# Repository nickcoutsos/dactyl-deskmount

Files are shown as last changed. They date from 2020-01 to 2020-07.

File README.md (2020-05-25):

# dactyl-deskmount
---
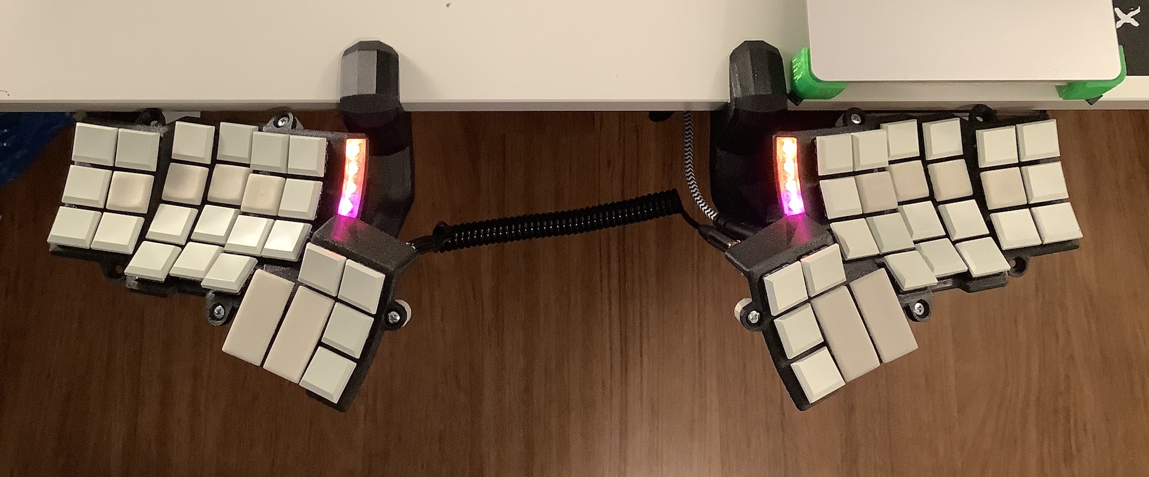
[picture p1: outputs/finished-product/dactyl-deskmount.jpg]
Dactyl and desk mounting hardware


_[(3D Preview of assembled keyboard)](outputs/preview.stl)_

_[(More photos of the finished product)](outputs/finished-product/)_

## Goal

Essentially, make a variant of the [dactyl-keyboard] that doesn't impose
significant extra height above my desk surface.

I previously designed and built the "[dactyl-flatpacked]", a Dactyl made from
slotted acrylic pieces instead of 3D printed, and ended up loving the keyboard.
Like most non-planar keyboards it has an issue with overall height. The lowest
row requires my wrist/palm needs to clear around 4cm, and unfortunate
combinations of desk-chair-user height can exacerbate things. Ultimately it has
taught me to properly float my wrists while typing, but I still wanted to see
what else could be done.

Another goal I had was to have a pure and simple OpenSCAD version of the dactyl
that wouldn't require the complexity of compiling and executing Clojure to
generate unreadable OpenSCAD code. This part started out pretty well but over
time I got tired of limitations around code organization and stopped trying so
hard to keep features modular while still having something aesthetically
pleasing.

I still stand by working directly in OpenSCAD, but if I were to start
over or dedicate significant time to refactoring I would look into more of the
community OpenSCAD libraries for things like generating hulls from profiles
instead of mimicking triangle hulls and such that I saw in the origin dactyl
code.

## Inspiration

Through the mechanical keyboard subreddit I came across a couple of keyboard
mounting designs that helped me see the possibility of using ball-and-socket
mounts.

**ElliotCable: [Ergovox]**

This ergodox keyboard uses RAM mounts screwed into the bottom of a standing desk
allowing for a fully vertical (or any angle, really) keyboard orientation.

**Martin Körner: [Georgi stand with trackball]**

This georgi uses ball camera mounts attached to a tripod, removing the desktop
from the equation altogether. With the tripod you can precisely control height
and the trackball mount is a nice bonus as well.

## Design Considerations

**Desk mounted via clamps**

The tripod stand is cool but I work at a desk. Unfortunately when I'm in the
office it isn't my desk so stability is sacrificed to avoid drilling holes.

**Camera ball mounts**

I don't want to go to all the trouble of building a keyboard only to wonder if a
steeper tenting angle would be better. I also get to control the pitch and yaw
if I like. I had a lot of misgivings about this. Ideally it would be positioned
so that the majority of the the force put into the keyboard goes straight
through the ball to avoid torque causing the ball to slip.

Unfortunately putting the ball mount directly underneath my hand would take up
room underneath the keyboard and cause problems for the sitting position. I made
the concession of offsetting the mount a little with the hope that by the time I
begin to see obvious slippage I will have found an angle I like and print static
arms to clamp onto my desk. Worst case scenario, I can print a more traditional
base and use the keyboard on my desktop like an animal.

**Keycaps and layout**

I use choc low-profile switches because I had them leftover from an earlier
iteration I didn't end up liking. I designed and printed custom variations of
the 2u keycaps (because, quite simply, I like the Dactyl's thumb cluster) and
deep-dished homing keycaps.

The same positioning algorithm from the original Dactyl is used but with a
slight outward pivot of the pinky columns, and removed keys:

* no number row because I hate it
* pinky keys removed from row 4

Were I a braver person I would remove even more keys (the entire pinky columns)
and learn to love QMK combos but I never properly made sense of the config
options like `PERMISSIVE_HOLD` and `IGNORE_MOD_TAP_INTERRUPT` which made for a
bad experience in the past.

**LEDs**

I want to have visual indicators for things like Caps Lock (because I find caps
lock useful) and potentially notifications pushed from the host via Raw HID.
Admittedly I do think a few subtle lights can add to the keyboard's aesthetics.

## Mounting hardware

* 3d printed desk clamps
  * I include a cutout for 1/4"x5/16" tee-nut.
  * a 1/4"-20 x 1 1/4" hex bolt (with 3d printed knob and swivel plate) are used
    for tightening.
* 1/4" ball mount (I used a [ball mount tripod adapter] from AliExpress)
  * This attaches to my 3d printed clamp via a couple of m4 screws
* 3d printed keyboard bottom mount attached to the top of the ball mount via
  another tee-nut.
    * at the beginning I set out to use heat-set inserts like I've seen on many
      other projects but couldn't find a source for the right kind in a useful
      quantity.
    * I'm finding tee-nuts to be incredibly useful in 3d printed projects when I
      want to securely fasten things to a single screw.
* 3d printed keyboard plate attaches to 3d printed mount via m3 screws.
  * the design uses three m3 mounting holes on the keyboard plate matching up
    with three holes on the mount (one on the far edge of the thumb cluster and
    two at the top and bottom of the index finger column).
  * there are two more unused screw holes on the pinky finger column in case I
    want to re-design a more robust bottom mount.
* another 3d printed mount hanging underneath the thumb cluster holds a 24-pin
  wide IC socket for the pro micro controller. Ribbon cables conned the socket
  pins to the keyboard matrix and TRRS socket. A stripped micro USB connector
  connects from a sturdier micro USB socket breakout board to the pro micro.

## Pre-rendered parts

All printable pieces are pre-rendered (for my specific setup) and available in
[outputs/pre-rendered/](outputs/pre-rendered):

* [bottom-mount](outputs/pre-rendered/bottom-mount.stl)
* [choc-keycap-1u](outputs/pre-rendered/choc-keycap-1u.stl)
* [choc-keycap-1u-index](outputs/pre-rendered/choc-keycap-1u-index.stl)
* [choc-keycap-2u](outputs/pre-rendered/choc-keycap-2u.stl)
* [clamp-knob](outputs/pre-rendered/clamp-knob.stl)
* [clamp-swivel-plate](outputs/pre-rendered/clamp-swivel-plate.stl)
* [led-diffuser](outputs/pre-rendered/led-diffuser.stl)
* [plate](outputs/pre-rendered/plate.stl)
* [socket-mount](outputs/pre-rendered/socket-mount.stl)
* [table-hook](outputs/pre-rendered/table-hook.stl)

[dactyl-keyboard]:https://github.com/adereth/dactyl-keyboard/
[dactyl-flatpacked]:https://github.com/nickcoutsos/dactyl-flatpacked/
[Georgi stand with trackball]:https://stenoblog.com/georgi-stand-with-trackball/
[Ergovox]:https://www.reddit.com/r/MechanicalKeyboards/comments/8ib8pi/something_a_little_different_the_ergovox/
[ball mount tripod adapter]:https://www.aliexpress.com/item/4000183944867.html

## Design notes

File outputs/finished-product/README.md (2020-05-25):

# Finished product

## Top view

Assembled keyboard in use

This is my home computer setup as of 2020-05-18. A cheap IKEA sit/stand desk, my
newly completed desk-mounted dactyl keyboard, and an older Apple Magic Trackpad.

In this shot you can also see the LEDs running an animation I made to just cycle
through a narrow range of hues to avoid being too jarring. Eventually this will
signal notifications on the host computer but for now I have the lights turned
off.

Earlier in the design of the keyboard I considered another mount to keep the
trackpad at the same level as the keyboard but I'm really surprised at how
comfortable it is to use positioned just past the right hand keyboard. This is
great for me because despite having switched to a trackball mouse several months
earlier, nothing beats precision scrolling.

## Below

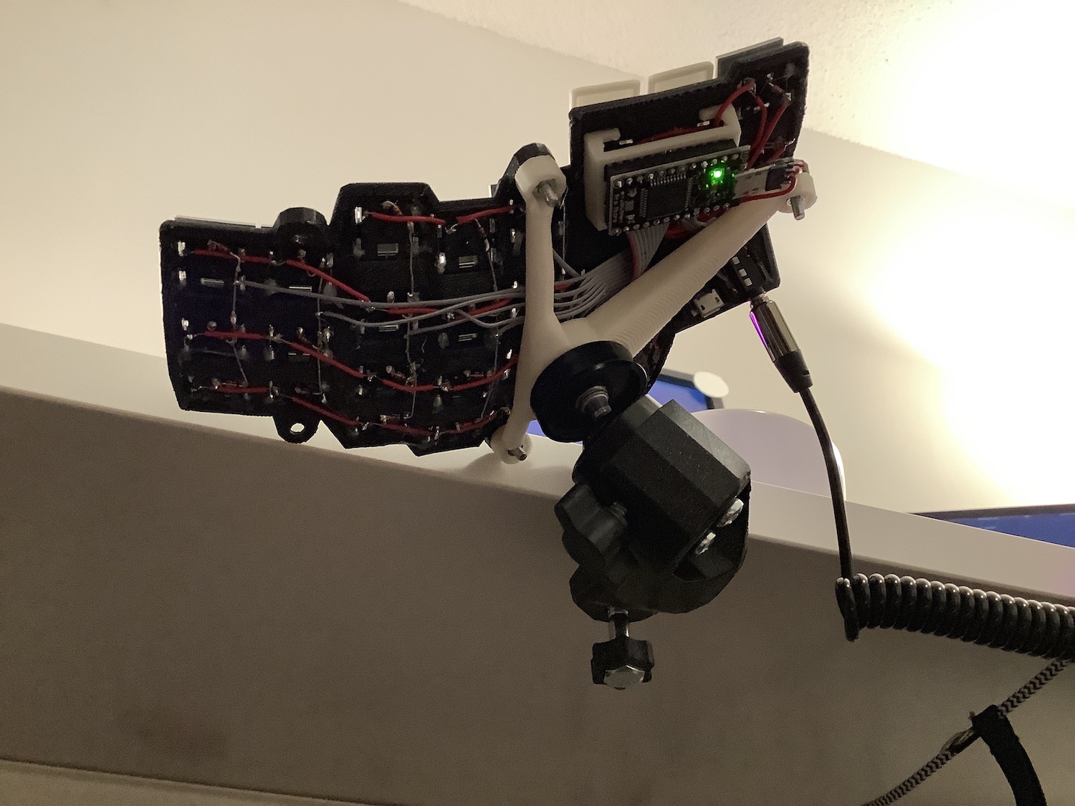
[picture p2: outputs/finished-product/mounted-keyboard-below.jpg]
Keyboard from below


The wiring is pretty exposed. I prefer this simplicity to a lot of the keyboard
cases that add height without giving you any real benefits. It's a DIY keyboard
already and, in my opinion, a fully enclosed case doesn't make it look more
professional.

I did have some concerns about having this in an office setting where delicate
components are exposed to stray dogs but that's moot for the foreseeable future.

Anywho, one other nice benefit to mounting this off the front of the desk is the
ability to run the USB cable under my desk and out of sight.

## Mount

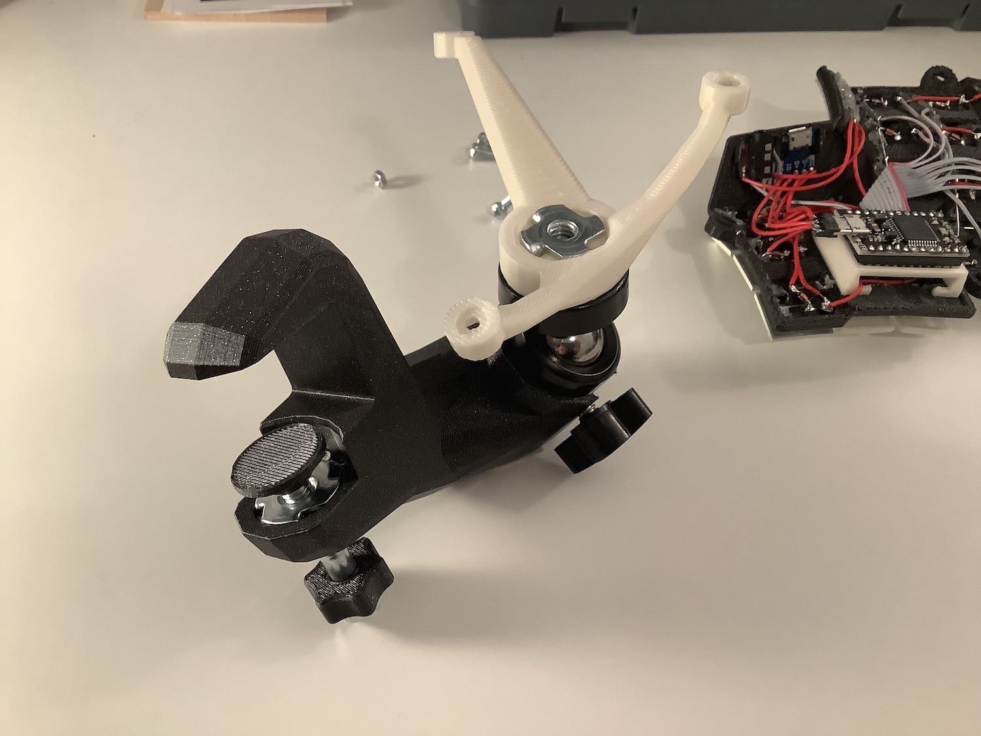
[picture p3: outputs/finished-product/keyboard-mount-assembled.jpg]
Mounting hardware assembled


This is the assembled keyboard mount without the keyboard.

The main black print is the [table hook](../pre-rendered/table-hook.stl) and in the clamp part (left) is the [swivel plate](../pre-rendered/clamp-swivel-plate.stl)
(it doesn't really stay in place when not clamped) sitting on top of a 1/4" hex
bolt screwed into a tee-nut and the hex head covered by a small comfortable
[knob](../pre-rendered/clamp-knob.stl).

The other end holds an off-the-shelf ball mount, and on top of that in white is
the [bottom mount](../pre-rendered/bottom-mount.stl) to which the keyboard 
attaches with 3 sets of m3 screws and nuts.

## Wiring

Here's a rough look at the wiring for the left half.

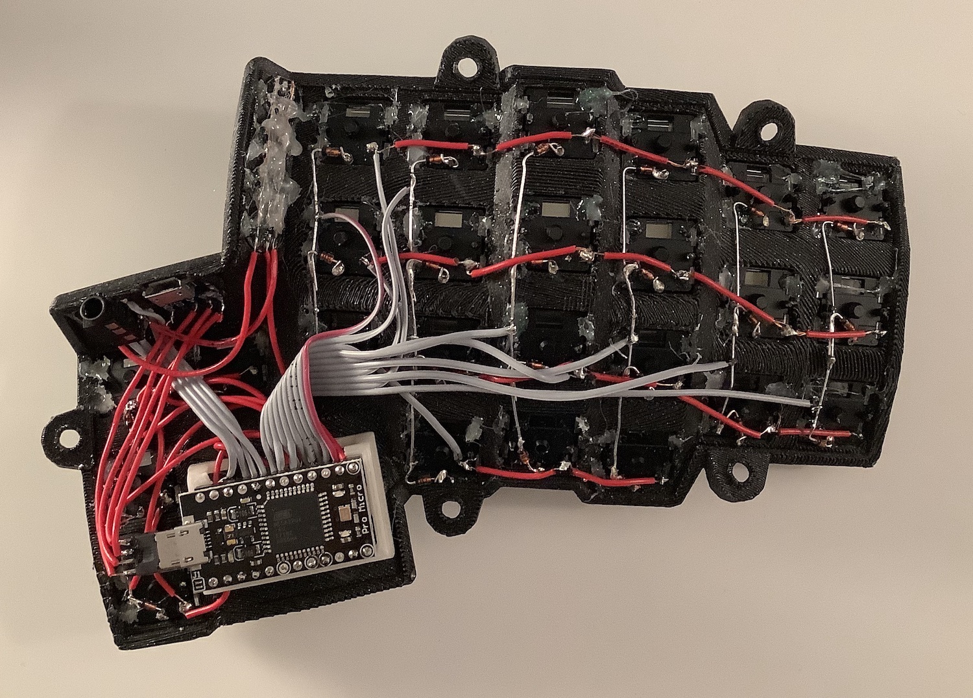
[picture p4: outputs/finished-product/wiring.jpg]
Left hand wiring


All of the switches are hot-glued into the plate for extra security. As an added
bonus these glue sticks contain glitter.

The finger cluster wiring is pretty clean considering I removed the diodes from
an earlier version for re-use, but the thumb cluster is where all the action is
and it's hard to see what's going on there.

Right over the 2u thumb keys I have the [socket-mount](../pre-rendered/socket-mount.stl)
super-glued and the 24-pin IC socket sits inside. A couple of ribbon cables 
connect it to the finger cluster and TRRS breakout board, as well as another 8
individual wires for the thumb matrix and the LED chain. Lastly, a gutted micro
USB connector connects the micro USB breakout board to the mounted pro micro.

The pro micro has diode leg pins to hold it firmly into place in the IC socket,
and with all of the other wires the socket doesn't actually need glue to stay in
place.

The LED column (left of all the finger switches) is hard to make out underneath
all of the hot glue. This is partly to make sure they stay in place but also to
shield the bare copper wires used to connect all of the VCC and GND pads.

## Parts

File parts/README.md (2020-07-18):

# Parts

OpenSCAD files in this directory are individually printable pieces used to
assemble the keyboard.

Files under `placeholders/` are approximations of existing parts (screws, PCBs,
etc.) that shouldn't be printed, but are used to help provide a clearer picture
of the assembly and/or for subtraction. These modules will often have optional
parameters like `$clearance` and `footprint` to help create appropriately sized
negative spaces in the printed pieces.

## Printable Parts

### `plate.scad`

This is the main component. It connects a number of plates arranged according to
the defined row and column sizes and curvatures. It also includes a trim made of
a quarter-round profiled edge, a space for a column of 3535 PCB LEDs and a few
m3-sized screw holes to attach to the keyboard's bottom-mount.

### `socket-mount.scad`

The socket mount gives me a place to attach my pro micro socket hanging below
the thumb cluster. When I assembled everything I ended up cutting out most of
the horizontal pieces so that I could solder directly to the socket before
gluing things down.

In retrospect, this could have been simplified and printed as part of the plate
itself but I was worried about how well it would come out given that it would be
printing on top of support material.

### `led-diffuser.scad`

I had few versions of this, but the idea is to print a very thin (1 line thick)
cover in transparent or light coloured filament to diffuse the LED light. It
worked ok. The important thing was to not blind anybody catching an eyeful of my
keyboard's lights, but printing it in translucent filament gives a very pretty
look. If you render the script standalone (instead of importing the module) its
in a standing position with manually generated support for printing stability.

In the end I settled on a solid pyramid-like pattern hoping to get interesting
refraction of the light, but if I were to do this again I would redesign the
plate so that this part doesn't have curves on multiple axis and cut a piece of
acrylic for the LEDs to shine through the edge.

### `bottom-mount.scad`

This may be the lightest piece that takes most of the strain. It attaches to the
ball mount (secured in place via a tee-nut) with arms extending to screw holes
on the plate that fasten via m3 screw and hex nut.

__**NEW:**__ after a bit of use I was happy with the stability fo the camera
mount, but the plate itself would flex a fair bit when pressing keys on outer
columns (particularly modifiers like shift and layer toggles where I'm holding
the key down). The bottom mount has been updated to add additional branches to
connect to the outer column screw holes, and all arms have been made thicker.

Now the main source of flex comes from the table hook.

### `table-hook.scad`

The table hook (which includes the `clamp.scad` part) is a holder for the ball
mount, a short arm, and a clamp that attaches to the edge of the desk. I have
a separate file for the clamp that that I could print and test it separately but
for consistency it should be moved and the table-hook file should include a
module that cuts it down to the testable printable section.

This piece can be printed without supports if you're ok a not-so-nice bottom
side (and that your printer is good enough but I guess that goes for everything)

### `choc.scad`

Most of my keyboard uses regular Kailh Choc 1u keycaps, but I made a custom
version to print my own 2u and scooped 1u (with bump) versions.

This is not the same as `placeholders/keycap.scad` which doesn't include the
stem or cavity (or surface detail).

## Plate "atoms"

Modules in this directory are the "atoms" that make up the full plate. On their
own they are useless but the intention is to hull the pieces together.

## Placeholders

Placeholder parts

_(left to right: `led`, `hex_nut`, `hex_bolt`, `socket`, `kailh_choc_keycap`,
`kailh_choc_switch`, `m3_nut`, `m3_screw`, `micro_usb_breakout`, `pro_micro`,
`tee_nut`, `trrs_breakout`)_

_(top to bottom: normal, `$detail=true`, `$detail=true; $clearance=1`)_

### `3535-led.scad`

Everything I do is handwired so surface mount components aren't really an option.
You can find ws2812b LEDs on individual PCBs (including capacitor and resistor)
which makes things a little easier, so I use them happily. This placeholder
accounts for the placement of the capacitor and resistor so that it can be
subtracted from the plate, leaving a helpful socket.

When soldering the chain of LEDs together I found it helpful to take a length
of wire, strip of the insulation, twist the strands together, and solder that
across each line of pads (VCC, DIn/DOut\*, GND) instead of cutting individual
wires and soldering them one at a time. 

\*Although VCC and GND on the LEDs are technically parallel, the signal line
is serial so if you do this you absolutely need to cut the wires to so that the
DI and DO pads of the same PCB are NOT connected.

### `ball-mount.scad`

This module gives me a visual of the ball mount part with a couple of extras:

1. I can render child modules that are "attached" to the mount
2. I can pass in transformations that it will apply to the base and mount to
   let me pivot things.
3. It will pass the inverse of those pivots to the child modules so that I can
   undo transformations as needed.

### `ic-socket.scad`

A 24 pin wide IC socket.

### `keycap.scad`

Rough approximation of a kailh choc keycap. It looks for OpenSCAD special
variables (`$u`, `$h`, and `$rot`) that may be set by the positioning module to
give us per-key customizations. The override definitions for the thumb cluster
makes use of this to implement the tall "vertical" keycaps as rotated "wide"
keycaps.

It can also look for `$key_pressed` to translate the keycap downward so you can
visualize the space between keys when pressed vs unpressed.

### `keyswitch.scad`

Rough approximation of a kailh choc keyswitch. This visual is helpful to plan
out where the switch pins will end up in the final layout, although I think I
might be the only person in the world not rotating them 180 degrees so that the
pins face "North".

### `m3-hex-nut.scad`, `m3-screw.scad`

As advertised, more or less.

### `micro-usb-breakout.scad`, `trrs-breakout.scad`

These are only going to be so useful. I wanted a Micro USB socket (and breakout
board because I can't solder those tiny contacts) so I don't have to worry about
breaking the Pro Micro's connector but this is only useful if you use a breakout
with the same dimensions. Same goes for the TRRS breakout except even less ideal
because the breakout boards I sourced are bigger than this but I cut them down
to save space and keep symmetry.

### `promicro.scad`

This is based on a black Pro Micro from AliExpress.

### `table.scad`

Just a rectangle. I made the corners round to be fancy.

### `tee-nut.scad`

This is a 1/4"-20 (coarse thread) 5/16" tall tee nut I found in a nearby
hardware store. I'd like to think that any differences between what I used and
what you have available can be solved with adjusted `$clearance` values or a
little bending and cutting.

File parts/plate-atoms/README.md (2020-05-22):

# Plate "atoms"

These are the broken down pieces that get hulled and unioned together in various
ways to make up the full plate. With the exception of the test-fitting with the
LED sockets and choc-plate modules there's no reason to render and print any of
these on their own.

## Part descriptions

### `trim.scad`, `trim-profile.scad`

This code is probably the hardest to follow and maintain out of the entire repo.
It involves a lot of deliberate planning and tweaking to account for any changes
to configuration in the `definitions.scad` file. Ideally the trim module would
use the key placement configuration, perhaps with some details about how the
thumb and finger clusters connect, and then generate a perimeter around that.

### `choc-plate.scad`

There isn't much to this one. The keyhole size is configured in `definitions`
but it should probably exist here since it's specific to the Kailh Choc switch
(as are the cutouts for the switch to clip onto).

It considers the `$u`, `$h`, and `$rot` special variables and the
`plate_dimensions` determined in `definitions.scad` for orientation and size.

### `corner.scad`, `edge.scad`

These are small volumed solids that use the configured `plate_thickness` to hull
together and make up an appropriately thick plate. They are deliberately very
thin (the corner's dimensions are `[0.01, 0.01, plate_thickness]`) to avoid
strange artifacts if they happen to be positioned too closely together.

The `plate_edge` works like `plate_corner` but also takes into consideration the
key `$u`, `$h` special variables, and accepts a boolean `horizontal` flag to
determine orientation.

### `led-sockets.scad`

As mentioned in the definitions file, there is a column of LEDs positioned in
part as if it were a scaled down finger column. This module is basically a
trough with holes in bottom for a strip of PCB-mounted LEDs to mount and shine
through from underneath.

This mounting point is recessed so that it can be covered with a diffuser.

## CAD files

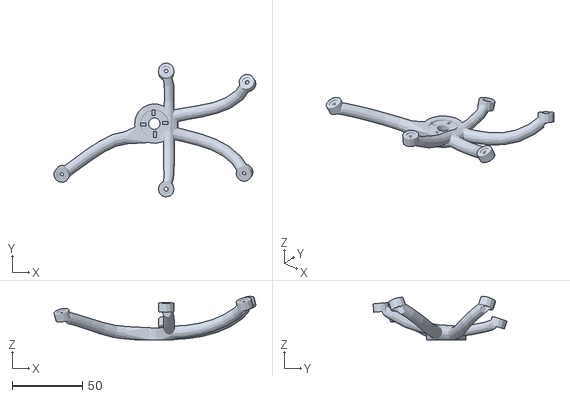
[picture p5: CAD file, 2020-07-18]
outputs/pre-rendered/bottom-mount.stl
143.4 x 95.1 x 30.9

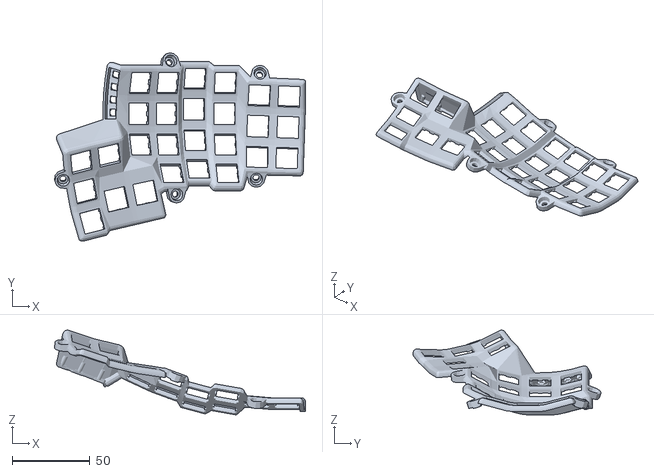
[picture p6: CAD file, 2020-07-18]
outputs/pre-rendered/plate.stl
161.6 x 121.3 x 54.7

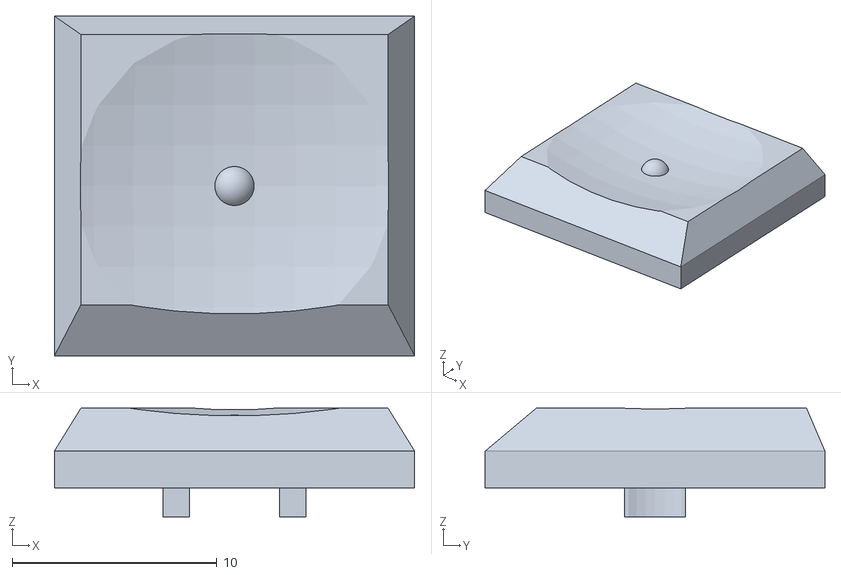
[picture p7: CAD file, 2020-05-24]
outputs/pre-rendered/choc-keycap-1u-index.stl
17.6 x 16.6 x 5.30

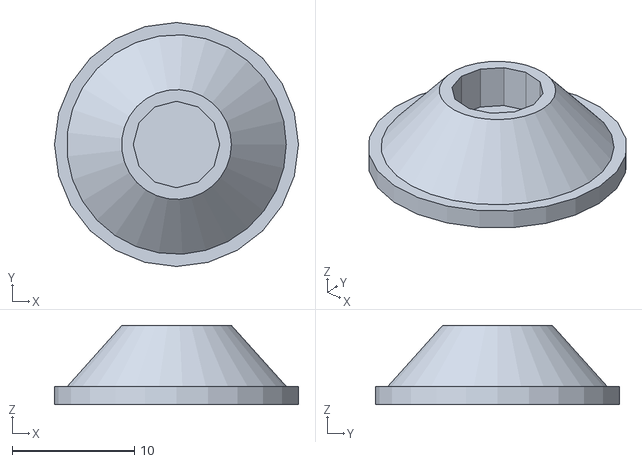
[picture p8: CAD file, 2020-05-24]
outputs/pre-rendered/clamp-swivel-plate.stl
20.0 x 20.0 x 6.50

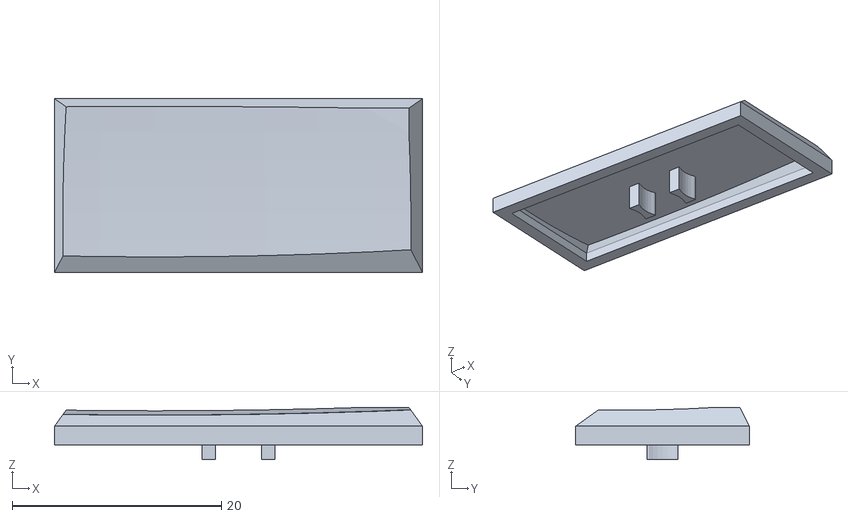
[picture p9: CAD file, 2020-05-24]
outputs/pre-rendered/choc-keycap-2u.stl
35.2 x 16.6 x 5.00

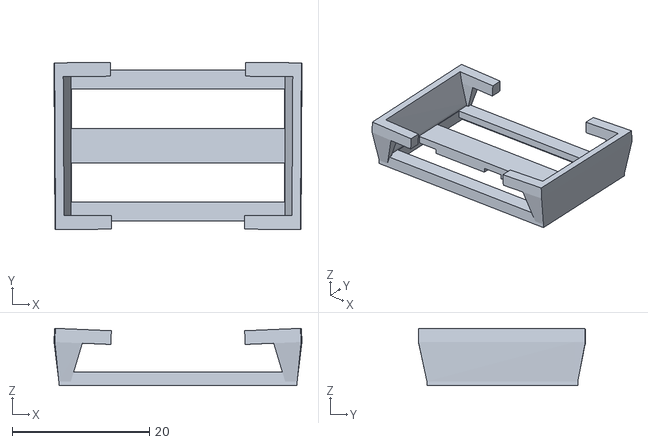
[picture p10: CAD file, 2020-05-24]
outputs/pre-rendered/socket-mount.stl
36.2 x 24.3 x 8.37

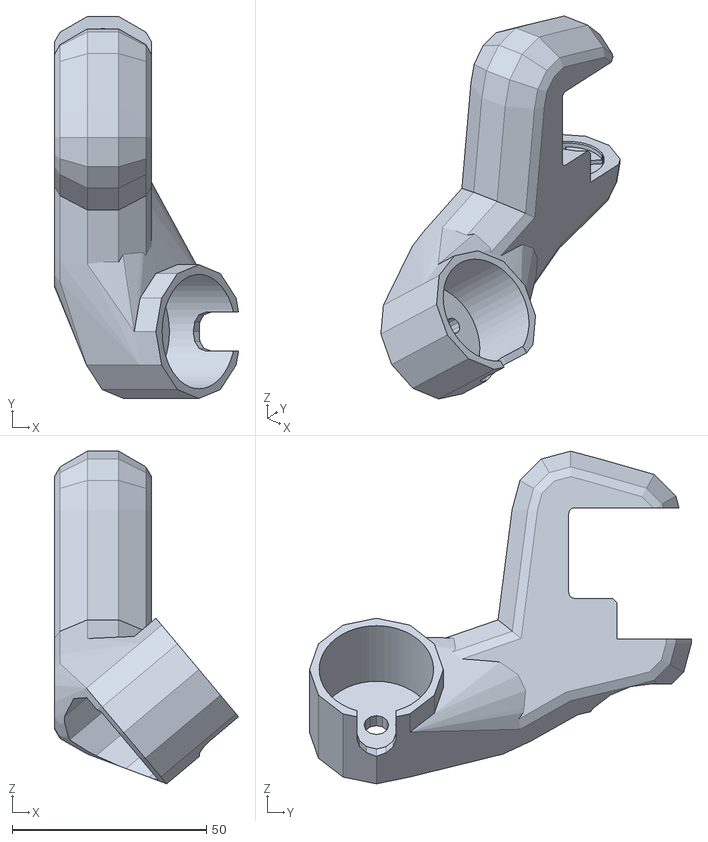
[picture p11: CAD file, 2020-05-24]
outputs/pre-rendered/table-hook.stl
47.4 x 98.3 x 85.6

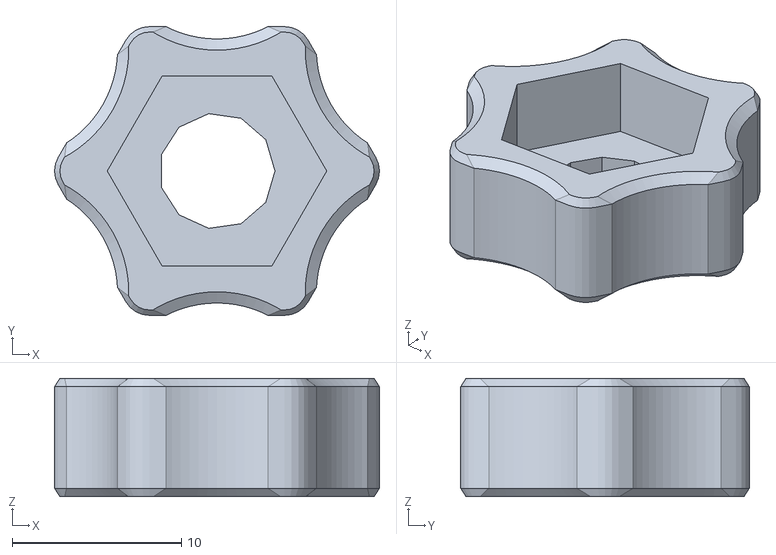
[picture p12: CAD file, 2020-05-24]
outputs/pre-rendered/clamp-knob.stl
19.2 x 17.1 x 7.00

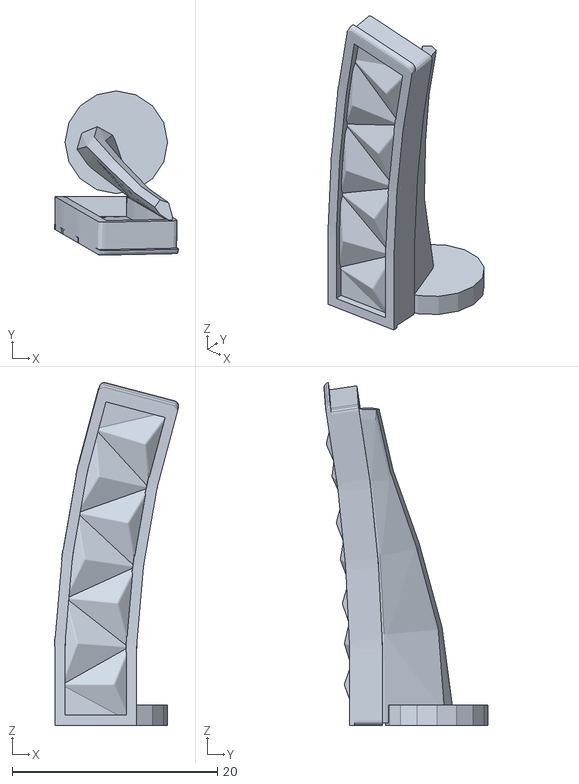
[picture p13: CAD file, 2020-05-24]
outputs/pre-rendered/led-diffuser.stl
12.1 x 16.0 x 33.4

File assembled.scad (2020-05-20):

use <scad-utils/linalg.scad>
use <scad-utils/transformations.scad>

use <parts/bottom-mount.scad>
use <parts/table-hook.scad>
use <parts/plate.scad>
use <parts/placeholders/ball-mount.scad>
use <parts/placeholders/m3-hex-nut.scad>
use <parts/placeholders/m3-screw.scad>
use <parts/placeholders/micro-usb-breakout.scad>
use <parts/placeholders/tee-nut.scad>
use <parts/placeholders/promicro.scad>
use <parts/placeholders/table.scad>
use <positioning.scad>
use <util.scad>
include <definitions.scad>

$fn = 12;

// translate(desk_top_offset) table();
// mirror_axes([[1, 0, 0]]) translate([80, 0, 0])
ball_mount() {
  color("goldenrod") tee_nut();
  bottom_mount();

  translate(-[0, 0, 15.05+8.47])
  multmatrix($inverse_pivot_transform)
  table_hook([-26, 0, 0], $render_accessories=true);

  multmatrix(keyboard_offset) {
    assembled_plate($detail=true);
    accessories(
      $render_controller=true,
      $render_leds=true,
      $render_switches=true,
      $render_keycaps=true,
      $render_trrs=true,
      $key_pressed=false
    );

    for (i=[0:2]) post_place(i) {
      m3_screw();
      translate([0, 0, -7]) m3_hex_nut();
    }
  }
}

/// samples for test prints
// intersection() {
//   difference() {
//     mount();
//     tee_nut($clearance=1, footprint=true);
//     multmatrix(keyboard_offset) assembled_plate();
//   }

//   // ball mount socket
//   // table_hook([-26, 0, 0]);
//   // rotate(90, Z)
//   // rotate(60, X)
//   // rotate(180, Z)
//   // translate([0, 0, -25])
//   //   cylinder(d=40, h=10, center=true);

//   // nut holder
//   // #translate([10, -42, 22]) cylinder(d=12, h=12, center=true);
//   // base
//   // #translate([0, 0, -1]) cylinder(d=30, h=15);
// }

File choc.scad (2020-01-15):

include <definitions.scad>

module choc_keycap(height=3.5) {

  u = !is_undef($u) ? $u : 1;
  h = !is_undef($h) ? $h : 1;
  scoop = max(0, min(1, is_undef($scoop) ? 0 : $scoop));

  width = 17.6 * u;
  depth = 16.6 * h;
  thickness = 1.5;

  top = !is_undef($key_pressed) && $key_pressed == true ? 2.18 : (cap_top_height - height);

  detail = is_undef($detail) ? false : $detail;

  sphere_radius = (1 - scoop) * 150;
  sphere_offset = 2.825;

  module outer() {
    hull() {
      linear_extrude(height=.1) square([width, depth], center=true);
      translate([0, 0, 1.7]) linear_extrude(height=.1) square([width, depth], center=true);
      translate([0, 0.8, height]) linear_extrude(height=.1) square([width - 2.6, depth - 3.4], center=true);
    }
  }

  module inner() {
    translate([0, 0, -thickness/2])
    hull() {
      linear_extrude(height=.1) square([width - thickness*2, depth - thickness*2], center=true);
      translate([0, 0, 1.7]) linear_extrude(height=.1) square([width - thickness*2, depth - thickness*2], center=true);
      translate([0, 0.8, height]) linear_extrude(height=.1) square([width - 2.6 - thickness*2, depth - 3.4 - thickness*2], center=true);
    }
  }

  module scoop() {
    scoop_offset_x = u * (is_undef($scoop_offset_x) ? 0 : $scoop_offset_x);
    scoop_offset_y = h * (is_undef($scoop_offset_y) ? 0 : $scoop_offset_y);
    scale([u, h, 1])
    translate([0, 0, sphere_offset + sphere_radius])
    translate([scoop_offset_y, scoop_offset_y, 0])
    rotate([90, 0, 0])
    sphere(r=sphere_radius, $fa=1);
  }

  module bump() {
    translate([0, 0, sphere_offset])
    translate([0, 0, sphere_radius - .25])
    translate([0, 0, -sphere_radius])
    difference() {
      sphere(d=2, $fn=48);
      translate([0, 0, -1]) cube(2, center=true);
    }
  }

  translate([0, 0, top])
  union() {
    difference() {
      union() {
        difference() { outer(); inner(); }
        intersection() { translate([0, 0, -thickness]) scoop(); outer(); }
      }

      scoop();
    }

    legs();

    if (!is_undef($bump) && $bump) bump();
  }
}


module legs() {
  $fn = 48;
  translate([5.7/2,0,-3.4/2+2])difference(){
    cube([1.3,3, 3.4], center= true);
    translate([3.9,0,0])cylinder(d=7,3.4,center = true);
    translate([-3.9,0,0])cylinder(d=7,3.4,center = true);
  }
  translate([-5.7/2,0,-3.4/2+2])difference(){
    cube([1.3,3, 3.4], center= true);
    translate([3.9,0,0])cylinder(d=7,3.4,center = true);
    translate([-3.9,0,0])cylinder(d=7,3.4,center = true);
  }
}

difference() {
  // original
  // choc_keycap();

  // deep scoop
  // choc_keycap(height=3.8, $scoop=0.81);

  // deep w/ bump
  choc_keycap(height=3.8, $scoop=0.81, $bump=true);

  // thumb
  // choc_keycap($u=2, $scoop_offset_y=-4);

  // translate([5, 0, 2]) cube([10, 20, 8], center=true);
}

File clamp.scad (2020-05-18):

use <scad-utils/transformations.scad>
use <placeholders.scad>
use <util.scad>
include <definitions.scad>

default_fn = 12;

clamp_offset = -[0, -16, desk_thickness + 2];
clamp_accessory_base = -4;

module clamp() {
  $fn = is_undef($fn) ? default_fn : $fn;

  hull() {
    translate(-[0, 5, desk_thickness + 17]) truncated_sphere(r=desk_arm_radius, rr=desk_arm_trunc);
    translate(clamp_offset) truncated_sphere(r=desk_arm_radius, rr=desk_arm_trunc);
    translate(clamp_offset + [0, 0, -10]) truncated_sphere(r=desk_arm_radius, rr=desk_arm_trunc);
    translate([0, 14, -4]) truncated_sphere(r=desk_arm_radius, rr=desk_arm_trunc);
    truncated_sphere(r=desk_arm_radius, rr=desk_arm_trunc);
  }
}

module clamp_base() {
  $fn = is_undef($fn) ? default_fn : $fn;
  translate(-[0, 5, desk_thickness + 17]) truncated_sphere(r=desk_arm_radius, rr=desk_arm_trunc);
}

module clamp_cutouts() {
  $fn=24;
  cut_diameter = desk_arm_thickness * 1.5;
  table($clearance=1);
  translate(clamp_offset + [0, 2 -11 + cut_diameter/2, 1]) cylinder(d1=cut_diameter - 2, d2=cut_diameter + 4, h=4, center=true);
  translate([0, 0, clamp_accessory_base]) {
    translate(clamp_offset + [0, 2 -11 + cut_diameter/2, -5]) cylinder(d=cut_diameter, h=12);
    translate(clamp_offset + [0, 2, -5]) rotate([0, 0, 45]) cylinder(d1=19, d2=21, h=1.5, center=true);
    translate(clamp_offset + [0, 2, -14]) rotate([0, 0, 45]) tee_nut($clearance=1);
    translate(clamp_offset + [0, 2, -14]) cylinder(d=6.35+0.5, h=20, center=true);
    translate(clamp_offset + [0, 5, -38]) rotate([0, 90, 0]) cylinder(d=43, h=desk_arm_thickness+1, center=true);
    translate(clamp_offset + [0, 2, -16.5]) cylinder(d1=9, d2=6.35, h=3, center=true);
    translate(clamp_offset + [0, 5+43/2, -38]) cube(43, center=true);
  }
}

module bolt() {
  bolt_height = 29.4;
  cap_height = 4.3;
  c = is_undef($clearance) ? 0 : $clearance;
  e = is_undef($extend) ? 0 : $extend;

  translate([0, 0, -c/2]) cylinder(d=6.35 + c, h=bolt_height + c + e);
  translate([0, 0, bolt_height - cap_height - c/2]) cylinder(d=12.47+c, h=cap_height+c + e, $fn=6);
}

module nut () {
  c = is_undef($clearance) ? 0 : $clearance;
  across_corners = 12.83;
  height = 5.56;
  cylinder(d=across_corners + c, h=height + c, $fn=6);
}

module knob() {
  difference() {
    lobed_cylinder(radius=8, h=7);
    translate([0, 0, 29.4]) rotate([180, 0, 0]) color("silver") bolt($clearance=0.5, $extend=5);
  }
}

module swivel_plate() {
  difference() {
    union() {
      cylinder(d=20, h=1.5, $fn=24);
      translate([0, 0, 1.5]) cylinder(d1=18, d2=9, h=5);
    }
    translate([0, 0, 3.5]) bolt($clearance=0.75);
  }
}

module swivel_plate_with_nut() {
  difference() {
    union() {
      cylinder(d=20, h=1.5, $fn=24);
      translate([0, 0, 1.5]) cylinder(d1=18, d2=15, h=4);
    }
    translate([0, 0, 3.5]) bolt($clearance=0.75);
    translate([0, 0, 1]) nut();
  }
}

module clamp_accessories() {
  color("goldenrod")
  translate(clamp_offset + [0, 2, -14])
  rotate([0, 0, 45])
    tee_nut();

  translate(clamp_offset + [0, 2, 1.75])
  rotate([180, 0, 0]) {
    color("silver") translate([0, 0, 4]) bolt();
    color("slategray") swivel_plate_with_nut();
    color("slategray") translate([0, 0, 34]) rotate([180, 0, 0]) knob();
  }
}

union() {
  $fn=12;
  table();
  difference() {
    clamp();
    clamp_cutouts();
  }

  translate([0, 0, clamp_accessory_base])
  clamp_accessories();
}

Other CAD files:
outputs/pre-rendered/choc-keycap-1u.stl
debug-helpers.scad
definitions.scad
geometry.scad
hook.scad
led-diffuser.scad
main.scad
mount.scad
parts/bottom-mount.scad
parts/choc.scad
parts/clamp-knob.scad
parts/clamp-swivel-plate.scad
parts/clamp.scad
parts/led-diffuser.scad
parts/placeholders/3535-led.scad
parts/placeholders/apple-magic-trackpad.scad
parts/placeholders/ball-mount.scad
parts/placeholders/choc-keycap.scad
parts/placeholders/choc-plate.scad
parts/placeholders/choc-switch.scad
parts/placeholders/hex-nut-and-bolt.scad
parts/placeholders/ic-socket.scad
parts/placeholders/kensington-orbit-trackball.scad
parts/placeholders/keycap.scad
parts/placeholders/keyswitch.scad
parts/placeholders/m3-hex-nut.scad
parts/placeholders/m3-screw.scad
parts/placeholders/micro-usb-breakout.scad
parts/placeholders/mx-plate.scad
parts/placeholders/mx-switch.scad
parts/placeholders/promicro.scad
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

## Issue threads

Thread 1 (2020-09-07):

are you open to commissions?

nicolasH, 2020-09-07:
Dear Mr. Coutsos

Would you be open to a commission? I would be interested in the following
- modifications of the design,
- set of 3d printed parts
- a completed keyboard

And if so how much would you charge and long would that take?

The design modification would be so that the thumb cluster would be removed and another one would be created in a different location.
my current thinking would be for it to be positioned below the index column.
It would be repositioned to be angled about 95° to 100° from the plate plane, like some kind of italic t, and it would be a 2 rows of 1.5 + 1 unit keys and a 1.5u key at the bottom about 100 degrees from the thumb plane.
Given my uncertainty with regard to the best placement and orientation for the thumb cluster i think the best thing would be If it was attached with a stiff but flexible wire of some kind on mounting points  under  the middle finger column.

please let me know if you would be interested in this commission.

Best regards,

Nicolas

nickcoutsos, 2020-09-07:
Hi Nicolas,

Thanks for your interest in my project but unfortunately I don't plan to take commissions.

I did put some effort into making the design (somewhat) modular but certain aspects make it difficult to accommodate radically different thumb cluster designs without writing a lot of manual code. If you have interest in attempting it yourself it's not impossible, just tedious.

Good luck, I hope you're able to find the right fit in a keyboard design. If you have any questions I'm happy to share what I know!

nicolasH, 2020-09-10:
thank you for taking the time to reply.

indeed i tried myself first, but ran in the tediousness of it rather quickly, hence this post.

best regards,

nicolas

Closed 2020-09-10.

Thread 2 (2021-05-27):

Build materials and keymaps

nulani38728, 2021-05-27:
Kudos on the ingenuity of this project, it's a superb idea. I really like the caseless, multi-pronged mounting bracket and the custom arm mount.

1. Do you have any recommended materials for the different printed components?
2. I was going to use the default firmware provided under `handwired/dacyl` in the qmk  repo and just add a custom keymap on top of that. Did you make any modifications to the firmware itself, or just the keymap? If so, can you share it?

Thanks!

nickcoutsos, 2021-05-27:
Hey, thanks for your interest!

All printed pieces were done in Prusament PLA. I don't know if PETG might helped with rigidity, though.

A while back I replaced the bottom mount with a version that's slightly thicker and extends to the screw mounts on the outer columns to prevent the plate from flexing too much, and since then I replaced the whole ball mount with static hooks (I think I still need to upload this). This gives me the most stability at the cost of any chance to play with different angles on the fly, which, trying to make adjustments with the ball mount just became tedious.

I used a custom firmware based on the split_common, but I think you should be able to use one of the existing dactyl implementations as long as you wire things correctly. My firmware wasn't anything special, aside from being specific to this 6x3+3 physical layout, but I did include a custom patch to make RGB matrix animations sync across both sides of the keyboard.

Ultimately, I've been using the keyboard for about a year now and aside from the changes I've described I'm also planning on switching to a more typical desk-top keyboard with the same layout.

* I find myself hating the low profile switches, at least for a contoured keyboard, and would switch back to my [dactyl-flatpacked](https://github.com/nickcoutsos/dactyl-flatpacked/) if I were less concerned about bulkiness
* Having slightly more desk space is nice, but having the keyboard sticking out makes it awkward to reach across my desk
* I think I don't care much about playing around with keyboard tilt and tenting, but not having a way to effortlessly move the keyboard halves around (and angle my wrists inward as appropriate) is too limiting.

That said let me know if you have any more questions, I'm happy to talk more about things!

nulani38728, 2021-05-28:
Thanks for the reply!

If you're considering going back to a desktop keyboard in this configuration, I'd recommend the Kinesis Advantage 2. If the height is an issue, a height adjustable desk is crucial here. I personally find having a second, smaller, and adjustable desk (essentially a giant keyboard tray) underneath the main desk to be a good solution if your upper desk is a fixed height.

There are a number of modifications you could make to this keyboard to enhance the experience -- can share some of those if you are interested.

I'm coming from using the KA2 as my main input device, but have developed RSI in the elbow from having the joint constantly bent. So for me, different tenting/tilting mechanisms are very attractive; I was thinking of using just the top part of your design on my existing tripod mount setup.

What I have rigged up now is Manfrotto clamps with articulating arms. This gives you a huge, 360 degree range of motion and enables configurations like standing and typing with arms at sides, sitting with different tilts, keyboards at sides of chair, etc. It's a bit ungainly and definitely adds a big contraption to your desk, but it's rock solid, and the arms are among the thinnest you can find. The 1/4 screw mount also lets me swap in microphones, cameras, or other accessories on the fly onto the arms.

You do have to fiddle with the knobs each time, but this is a necessary evil for the gains you get. You could also use a cold shoe/magnet mount to facilitate swapping input devices in and out, too.

I didn't have anything else like the Kinesis on hand, so I put a non-contoured split keyboard in a square matrix on the arms for now, but I'm finding it extremely difficult to use due to the lack of thumb clusters and key layout, which led to this saga to find something in a similar shape (Dactyl).

Thanks for the tip about the low profile switches. I was kind of intrigued by the Choc switches, since there is a 12g spring available, and that would be pretty nice for reducing strain, but the chiclet-style keycaps seem unpleasant (alien?) to use. I'll probably just stick to Gateron Clears if the low profile is not so good. I guess you never know until you try.

If you're planning to shelve this keyboard and go back to a desktop one, I'd be interested in buying it from you if it's not going to see any use -- would give me something ready made to experiment with. Just a thought.

Never did a from-scratch handwired build before, so I am approaching this with trepidation but enthusiasm.

nickcoutsos, 2021-05-29:
For what its worth, regarding the choc switches, I've only tried them here so I don't know whether it's the spring weight or the contours that makes me dislike them. I know others have built dactyls with choc switches. At some point I may try making a flat keyboard like the corne or gergo using these switches.

If you have any soldering experience at all then the only problem with handwiring is all of the wire cutting and stripping, and maybe trying to squeeze things into tight spaces if you try to keep the microcontroller tucked out of the away.

nulani38728, 2021-05-30:
I went ahead and printed it and have it partially done now, seems to not be too difficult in the end. I went with contoured keys I already had on hand. It was nice that you used a definitions file to make it modular. Thanks for the nice design!

nickcoutsos, 2021-05-30:
Awesome! I'd love to see pictures when you're ready :)

Closed 2021-06-25.

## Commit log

2019-11-21 Simple pure-openscad dactyl layout
    [definitions.scad, main.scad, positioning.scad]
2019-11-22 Placeholder key, switch, microcontroller, etc
    [placeholders.scad]
2019-11-22 Fix column curvature
    [definitions.scad]
2019-11-22 Start tweaking: remove number row, use kailh choc dimensions, remove number row
    [definitions.scad, main.scad]
2019-11-23 Tweak plate dimensions and pinky offset
    [definitions.scad]
2019-11-23 Move thumb overrides into positioning module
    [main.scad, positioning.scad]
2019-11-23 Move rotation into placeholders, add helpers to position at plate corners/edges
    [definitions.scad, placeholders.scad, positioning.scad]
2019-11-25 Add special variable to toggle key pressed state in switch/keycap
    [placeholders.scad]
2019-11-25 Join plates and add edge
    [main.scad, placeholders.scad, util.scad]
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2019-11-26 Fix edge/corner positioning for non-1u keys
    [positioning.scad]
2019-11-26 Add led column and connect everything
    [main.scad, placeholders.scad]
2019-11-27 Replace hardcoded values with variables
    [main.scad]
2019-11-27 Re-orient ball mount for easier rotation
    [placeholders.scad]
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2019-11-28 Attach to ball mount
    [main.scad, placeholders.scad]
2019-12-21 Move mount design into separate file
    [main.scad, mount.scad]
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2019-12-24 Redo mount arms under finger cluster
    [mount.scad]
2019-12-28 Move screw mounts into main
    [main.scad, mount.scad, positioning.scad]
2019-12-28 fix undef for special variable
    [placeholders.scad]
2019-12-30 Use "assembled_plate" module to include mounts and screw cutouts
    [main.scad, mount.scad]
2019-12-30 Add screws and nuts
    [mount.scad, placeholders.scad, positioning.scad]
2019-12-31 Fix screw mounts
    [main.scad, mount.scad, placeholders.scad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]
2019-12-31 Update tee nut dimensions
    [mount.scad]
2019-12-31 Diff plate from mount
    [mount.scad]
2019-12-31 Angle screw posts downward
    [main.scad, mount.scad, positioning.scad]
2019-12-31 Add intersection geometry to single out specific parts for test printing
    [main.scad, mount.scad]
2020-01-02 Slight angle to pinky columns
    [positioning.scad]
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2020-01-08 Adjust tee nut prongs
    [mount.scad]
2020-01-08 Fix clearances and make screw posts thicker
    [main.scad, mount.scad, placeholders.scad]
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2020-01-15 account for key press height in choc keycap
    [choc.scad]
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2020-01-15 Add test section for thumb cluster
    [main.scad]
2020-01-15 parametrize more variations of the keycap
    [choc.scad]
2020-01-15 Hide thumb cluster test cutout
    [main.scad]
2020-01-15 revert clip cutout change; we get a more snug fit when undersized
    [placeholders.scad]
2020-01-16 Fix up plate trim
    [main.scad, placeholders.scad]
2020-01-16 Add test cutout for two full rows of finger keys
    [main.scad]
2020-01-21 Clean up plate trim
    [main.scad]
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2020-01-23 Reduce plate thickness and keyswitch hole
    [definitions.scad, main.scad]
2020-01-23 Add more render options to mount
    [mount.scad]
2020-01-24 Fix up thumb/finger connection
    [main.scad]
2020-01-24 Add mount for trrs socket
    [main.scad, mount.scad]
2020-01-24 Fix socket orientation
    [main.scad]
2020-01-25 Fix usb breakout placeholder
    [placeholders.scad]
2020-01-25 Convenience special variable for activating all placeholder rendering
    [main.scad]
2020-01-25 Add usb socket mount
    [main.scad]
2020-01-31 Add separate printable mount for pcb socket
    [main.scad, mount.scad, placeholders.scad]
2020-02-01 Adjust thumb mount position
    [positioning.scad]
2020-02-03 Add beginnings of table hook
    [mount.scad, placeholders.scad, util.scad]
2020-02-03 Add test cutout for ball mount socket
    [mount.scad]
2020-02-03 Add clearance and rounding to ball mount socket
    [mount.scad]
2020-02-03 Start moving hardcoded ball mount params to definitions
    [definitions.scad, mount.scad, placeholders.scad]
2020-02-04 Move tee nut and table to placeholders
    [mount.scad, placeholders.scad]
2020-02-04 Add detail to desk clamp
    [hook.scad]
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2020-02-05 Break up clamp module, add bolt and knob
    [clamp.scad, mount.scad, placeholders.scad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]
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2020-02-05 Adjust ball mount socket hull, use matrix transforms for ball mount
    [definitions.scad, mount.scad]
2020-02-06 Make it easier to adjust clamp sphere resolution
    [clamp.scad]
2020-02-06 Update bolt size and knob
    [clamp.scad, util.scad]
2020-02-07 Round out some hard edges
    [clamp.scad, util.scad]
2020-02-07 Adjust fit for knob
    [clamp.scad]
2020-02-10 Break assembled hook out of mount module
    [mount.scad, table-hook.scad]
2020-02-10 Break down clamp components
    [clamp.scad]
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2020-02-12 Fix micro usb dimensions
    [main.scad, placeholders.scad]
2020-02-13 Refactor finger positioning, add extra screw holes
    [main.scad, mount.scad, positioning.scad]
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2020-02-18 Increase table gap in clamp, extend depth of top half
    [clamp.scad, definitions.scad]
2020-02-18 Move screw mounting holes over slightly
    [positioning.scad]
2020-02-19 Adjust fit for TRRS breakout
    [main.scad]
2020-02-19 Place with screw mount positioning, "fix" squishing of trim in interior corners
    [main.scad, placeholders.scad, positioning.scad]
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2020-02-21 Remove LED and move micro usb socket to thumb cluster
    [main.scad]
2020-02-22 Fix alignment of socket breakouts
    [main.scad]
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2020-05-20 Use correct LED size
    [3535-led.scad, plate.scad]
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2020-05-22 Fix import
    [clamp-knob.scad]
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2020-05-24 Add extra keycap and switch placeholders and make more specific measurement definitions
    [choc-keycap.scad, choc-plate.scad, choc-switch.scad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]
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2020-05-24 Have each part's scad file include default render with the settings I used
    [bottom-mount.scad, clamp-knob.scad, clamp-swivel-plate.scad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]
2020-05-24 Script rendering of all parts, include pre-rendered printable parts
    [bottom-mount.stl, choc-keycap-1u-index.stl, choc-keycap-1u.stl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]
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2020-05-31 straighten back plate and align with back of thumb cluster
    [plate.scad, positioning.scad, trim.scad]
2020-05-31 Approximate xda profile using squircles for my amusement
    [geometry.scad, xda-keycap.scad]
2020-06-15 thicken arms and adjust angles to make room around keyboard plate
    [bottom-mount.scad]
2020-07-18 Fix mesh errors in pre-rendered plate
    [plate.stl]
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
